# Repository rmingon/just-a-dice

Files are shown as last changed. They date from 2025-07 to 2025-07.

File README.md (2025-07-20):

# Just a Dice

An electronic dice based on the CH32V003 RISC-V microcontroller with bottom-mounted switch activation.

video (https://www.youtube.com/shorts/9gwGjO6Ar-I)

## Overview

This project is a compact electronic dice that uses bottom-mounted switch buttons for activation. Simply press the PCB from the bottom to activate the switches and generate a random number displayed on 6 LEDs arranged in a traditional dice pattern.

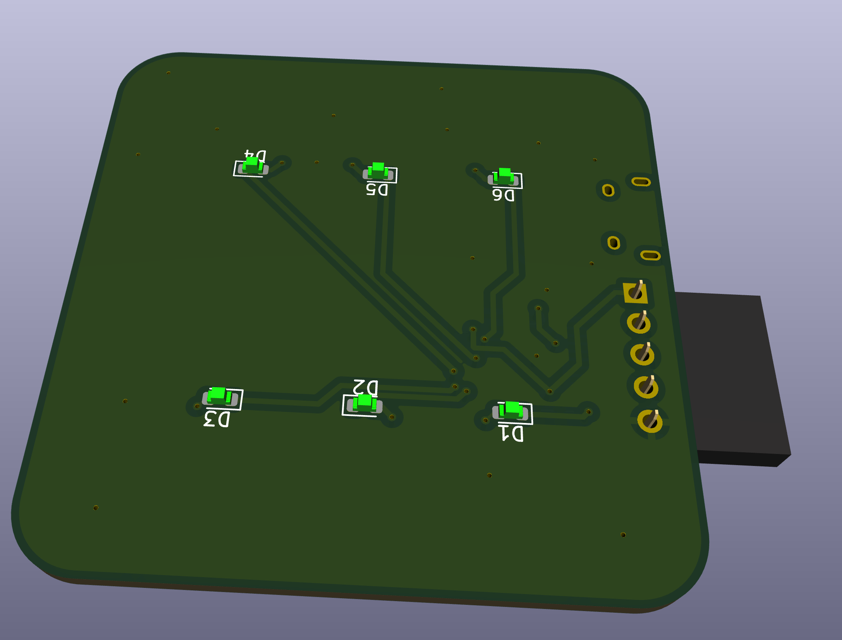
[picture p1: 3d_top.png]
PCB Top View

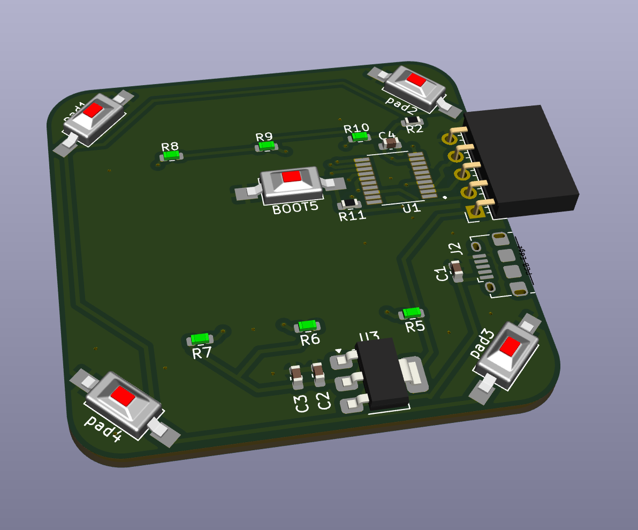
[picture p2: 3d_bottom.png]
PCB Bottom View


## Schematic and PCB Layout

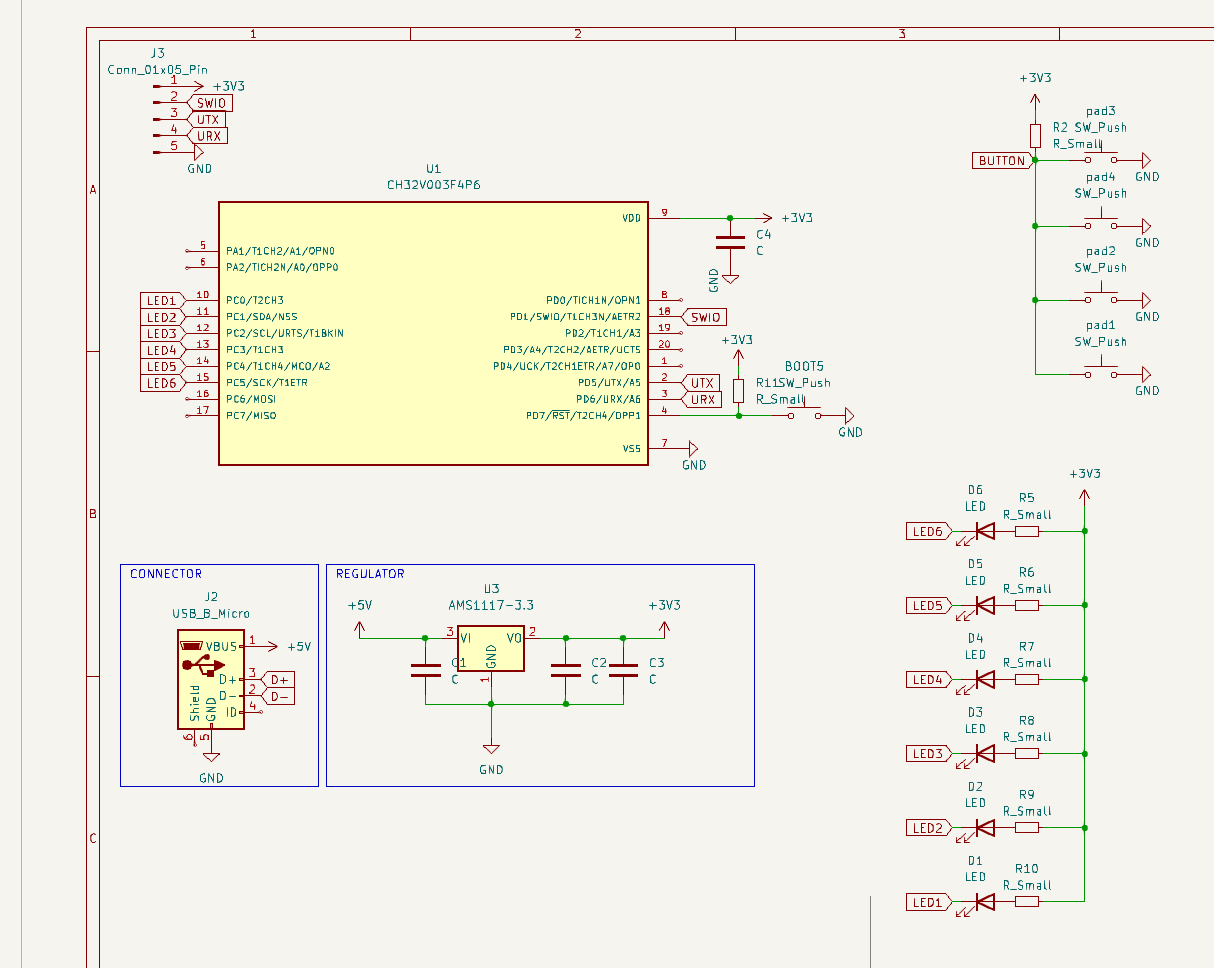
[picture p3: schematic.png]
Schematic

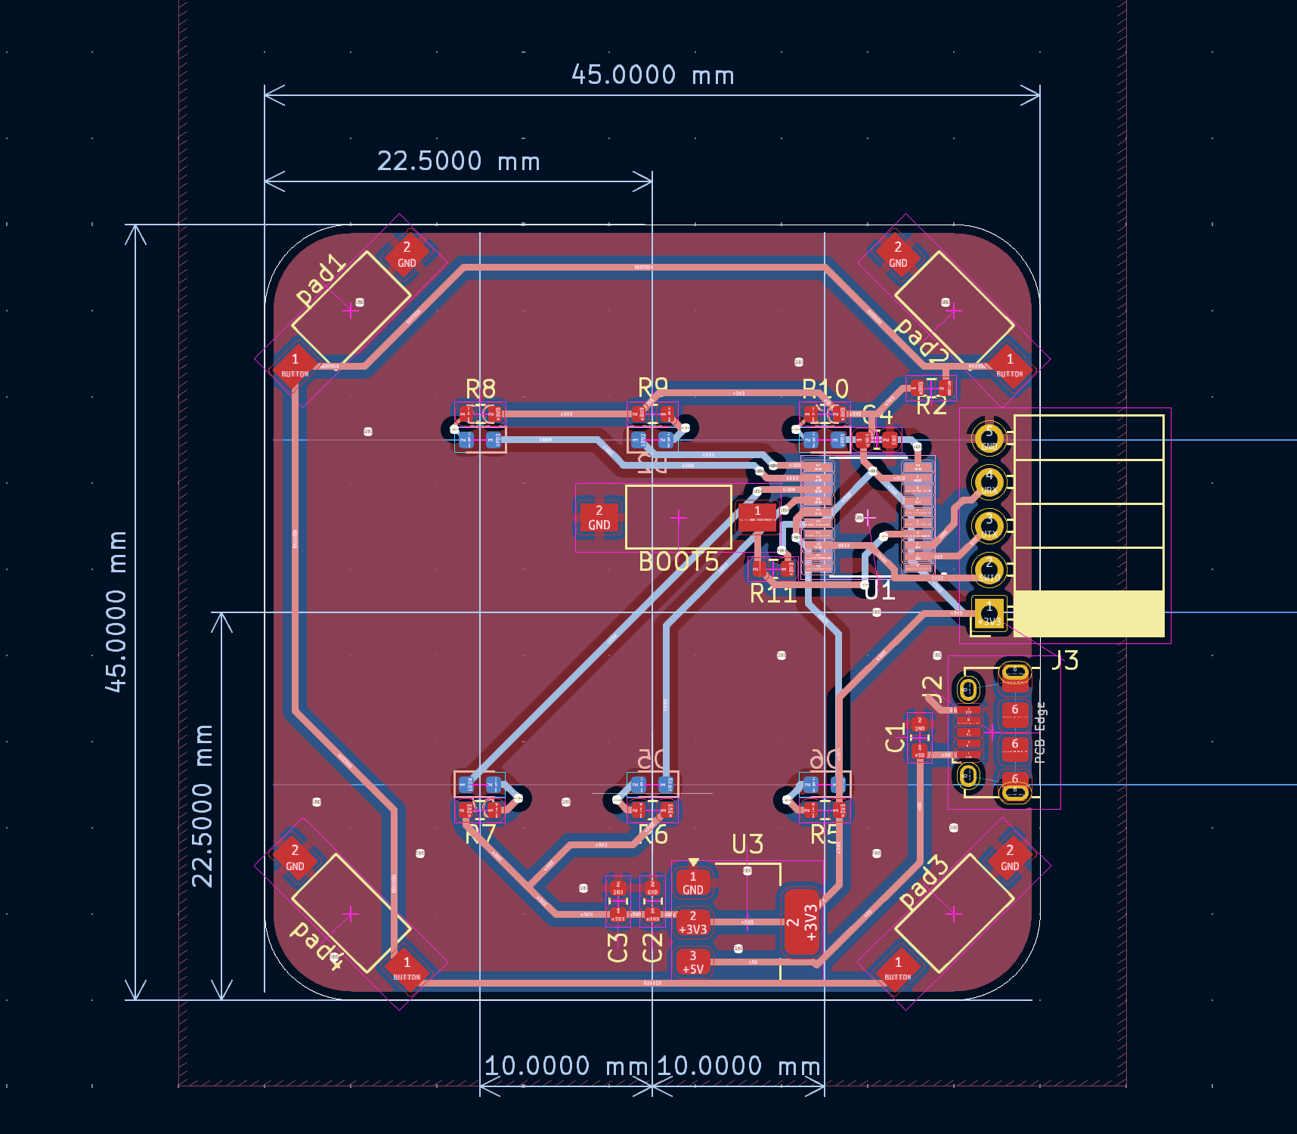
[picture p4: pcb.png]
PCB Layout


## Hardware Features

- **Microcontroller**: CH32V003F4P6 (RISC-V 32-bit)
- **Display**: 6 LEDs arranged in dice pattern (D1-D6)
- **Input**: 4 touch-sensitive pads on bottom (pad1-pad4)
- **Power**: Micro USB connector with onboard 3.3V regulation
- **Programming**: SWD interface with BOOT switch
- **Dimensions**: 45mm x 45mm PCB

## Components

- **U1**: CH32V003F4P6 microcontroller
- **U3**: AMS1117-3.3 voltage regulator
- **D1-D6**: LEDs for dice display
- **R5-R10**: Current limiting resistors for LEDs
- **J2**: Micro USB connector
- **J3**: SWD programming header
- **BOOT5**: Boot mode switch
- **C1-C4**: Decoupling capacitors

## How It Works

1. Power the device via micro USB
2. Press anywhere on the bottom of the PCB (touch pads)
3. The microcontroller generates a random number (1-6)
4. The corresponding LED pattern displays the result

## Programming

The CH32V003 can be programmed via the SWD interface using the onboard programming header (J3). Hold the BOOT switch while powering on to enter programming mode.

## License

This project is licensed under the CERN Open Hardware Licence Version 2 - Strongly Reciprocal (CERN-OHL-S).

## Files

- `hardware/`: KiCad PCB design files
- `schematic.png`: Circuit schematic
- `pcb.png`: PCB layout
- `3d_top.png`: 3D render of PCB top
- `3d_bottom.png`: 3D render of PCB bottom showing touch pads

## Getting Started

1. Assemble the PCB with all components
2. Program the CH32V003 with dice firmware
3. Connect via micro USB
4. Press the bottom to roll the dice!

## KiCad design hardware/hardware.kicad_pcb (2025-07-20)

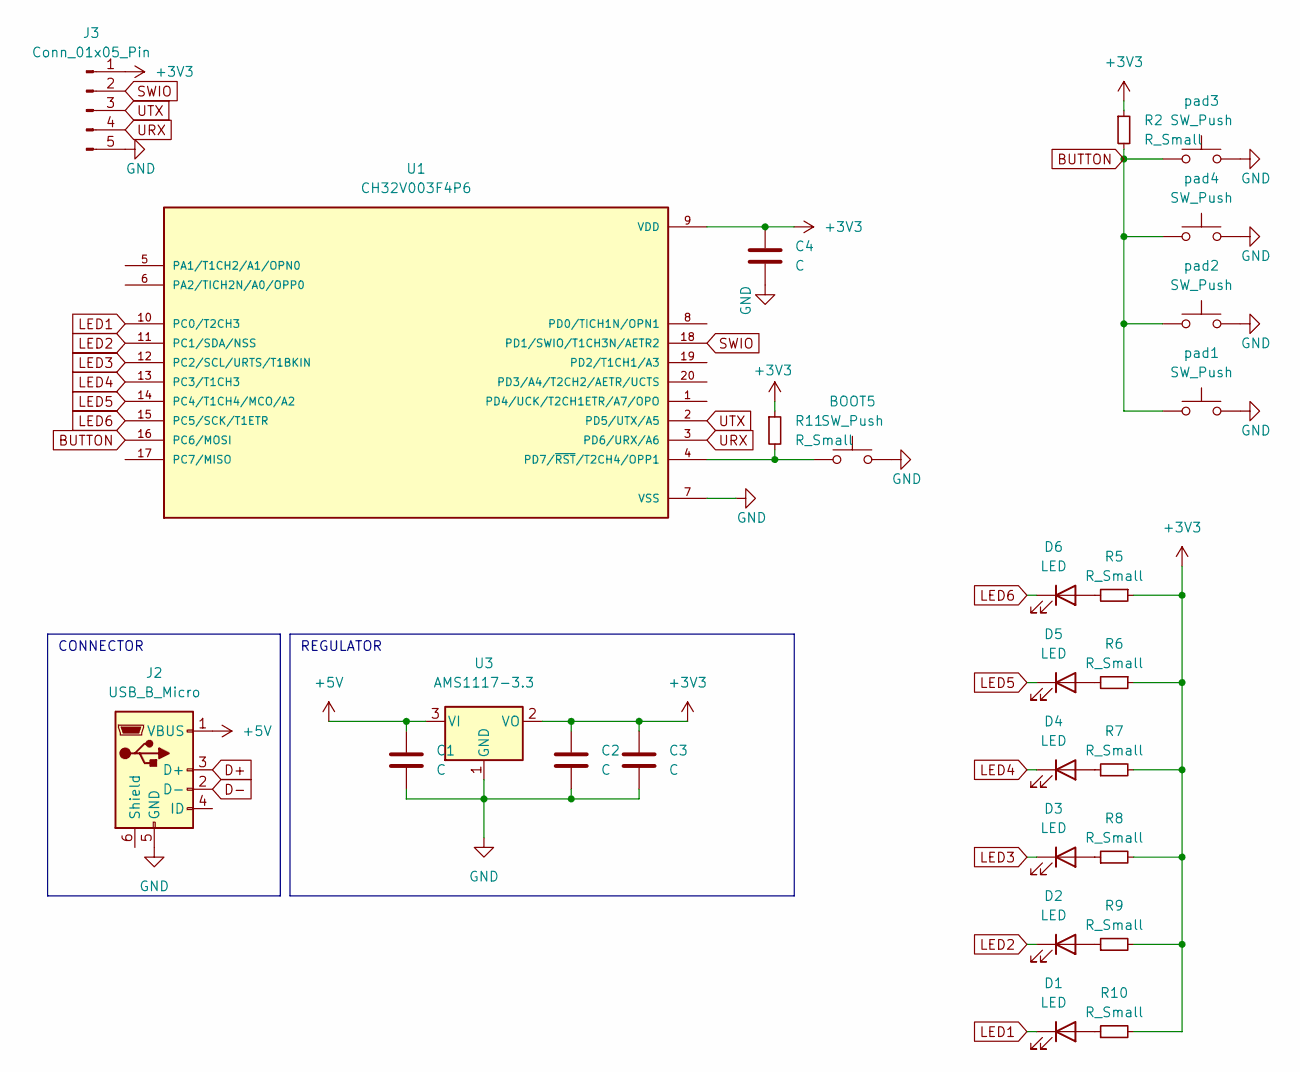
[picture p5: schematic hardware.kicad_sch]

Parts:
BOOT5: SW_Push; SW_SPST_FSMSM
C1, C2, C3, C4: C; C_0603_1608Metric
D1, D2, D3, D4, D5, D6: LED; LED_0603_1608Metric
J2: USB_B_Micro; USB_Micro-B_Amphenol_10118194_Horizontal
J3: Conn_01x05_Pin; PinSocket_1x05_P2.54mm_Horizontal
R2, R5, R6, R7, R8, R9, R10, R11: R_Small; R_0603_1608Metric
U1: CH32V003F4P6; SOP65P640X121-20N; PARTREV 1.4
U3: AMS1117-3.3; SOT-223-3_TabPin2
pad1, pad2, pad3, pad4: SW_Push; SW_SPST_FSMSM

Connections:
+3V3: C2.1, C3.1, C4.1, J3.1, R2.1, R5.1, R6.1, R7.2, R8.2, R9.2, R10.2, R11.1, U1.9 (VDD), U3.2 (VO)
+5V: C1.1, J2.1 (VBUS), U3.3 (VI)
BUTTON: R2.2, U1.16 (PC6/MOSI), pad1.1, pad2.1, pad3.1, pad4.1
D+: J2.3 (D+)
D-: J2.2 (D-)
GND: BOOT5.2, C1.2, C2.2, C3.2, C4.2, J2.5 (GND), J3.5, U1.7 (VSS), U3.1 (GND), pad1.2, pad2.2, pad3.2, pad4.2
LED1: D1.1 (K), U1.10 (PC0/T2CH3)
LED2: D2.1 (K), U1.11 (PC1/SDA/NSS)
LED3: D3.1 (K), U1.12 (PC2/SCL/URTS/T1BKIN)
LED4: D4.1 (K), U1.13 (PC3/T1CH3)
LED5: D5.1 (K), U1.14 (PC4/T1CH4/MCO/A2)
LED6: D6.1 (K), U1.15 (PC5/SCK/T1ETR)
unnamed: D1.2 (A), R10.1
unnamed: D2.2 (A), R9.1
unnamed: D3.2 (A), R8.1
unnamed: D4.2 (A), R7.1
unnamed: D5.2 (A), R6.2
unnamed: D6.2 (A), R5.2
unnamed: BOOT5.1, R11.2, U1.4 (PD7/~RST/T2CH4/OPP1)
SWIO: J3.2, U1.18 (PD1/SWIO/T1CH3N/AETR2)
URX: J3.4, U1.3 (PD6/URX/A6)
UTX: J3.3, U1.2 (PD5/UTX/A5)

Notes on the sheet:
CONNECTOR
REGULATOR

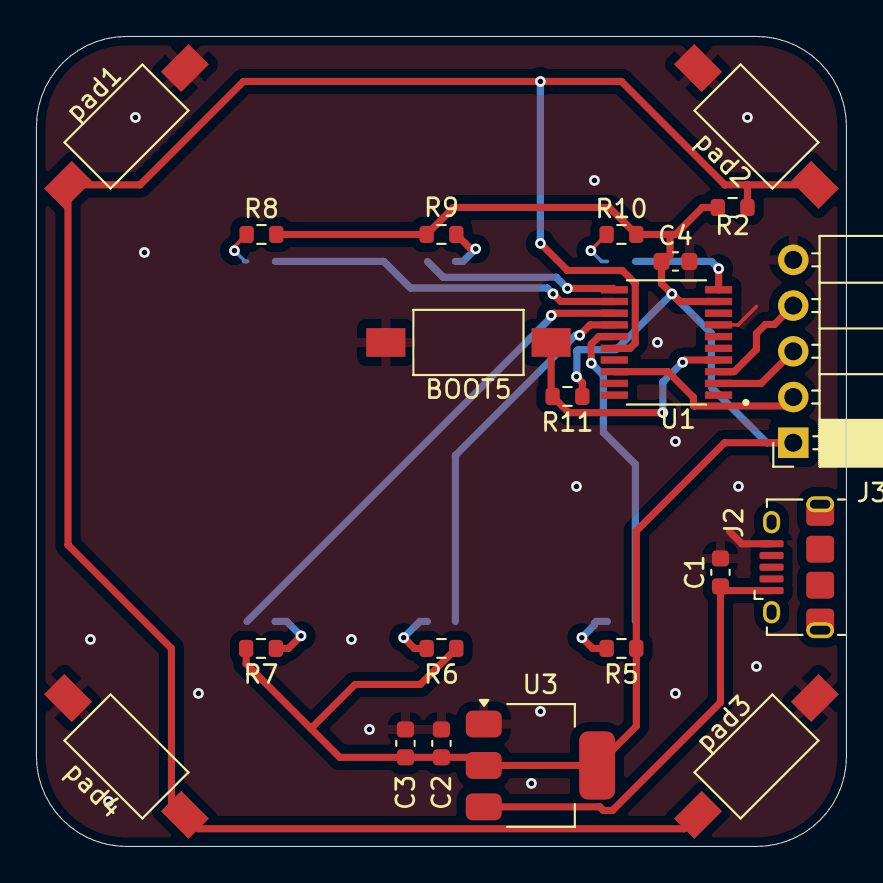
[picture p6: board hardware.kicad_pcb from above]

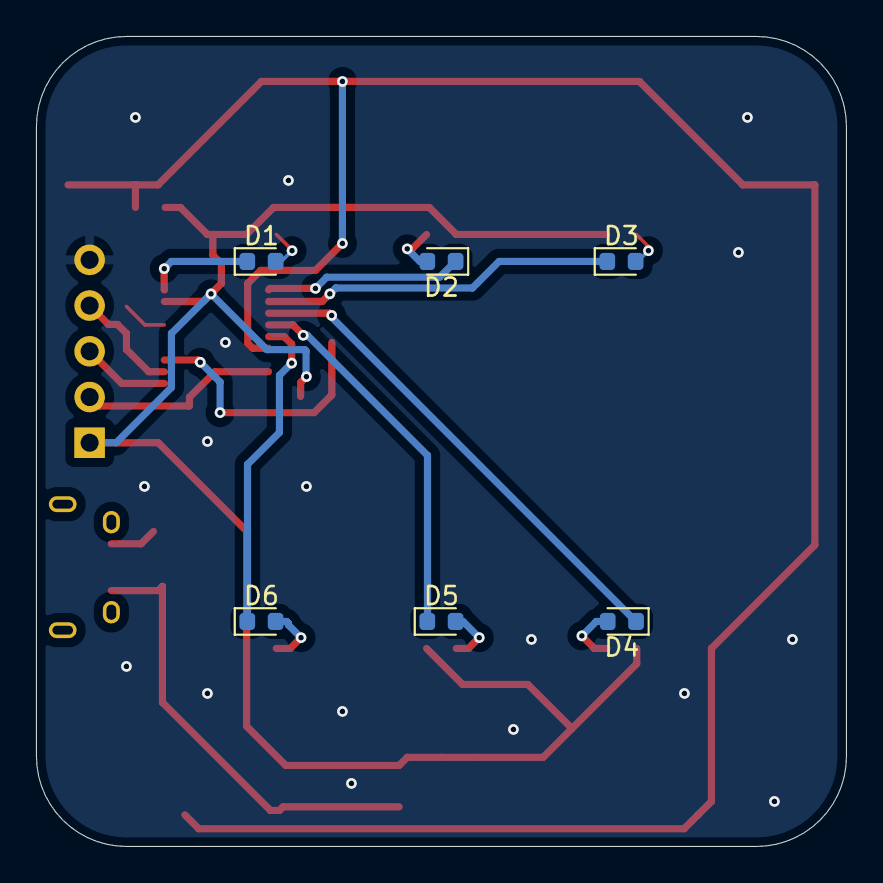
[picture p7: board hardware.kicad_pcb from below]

Board: 2 copper layers, 45.0 x 45.0 mm, 27 parts (6 on the bottom side), 20 nets.

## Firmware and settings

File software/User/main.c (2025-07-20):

#include "debug.h"
#include "ch32v00x.h"
#include "ch32v00x_gpio.h"
#include "ch32v00x_rcc.h"

// LED pin definitions (PC0-PC5)
#define LED_PORT GPIOC
#define LED0_PIN GPIO_Pin_0
#define LED1_PIN GPIO_Pin_1
#define LED2_PIN GPIO_Pin_2
#define LED3_PIN GPIO_Pin_3
#define LED4_PIN GPIO_Pin_4
#define LED5_PIN GPIO_Pin_5

// Button pin definition (PC6)
#define BUTTON_PORT GPIOC
#define BUTTON_PIN GPIO_Pin_6

// Dice patterns for LEDs (6 LEDs can represent dice faces 1-6)
// Alternative dice patterns (more dice-like representation)
const uint8_t dice_patterns[7] = {
    0b000000,  // 0 - Not used
    0b000100,  // 1 - Center LED (LED2)
    0b001001,  // 2 - LED0 and LED3
    0b001101,  // 3 - LED0, LED2, LED3
    0b011011,  // 4 - LED0, LED1, LED3, LED4
    0b011111,  // 5 - LED0, LED1, LED2, LED3, LED4
    0b111111   // 6 - All LEDs
};

// Global variables
volatile uint32_t delay_counter = 0;

// Function prototypes
void GPIO_Configuration(void);
void Display_Dice(uint8_t number);
void Clear_LEDs(void);
uint8_t Generate_Random_Dice(void);
void Simple_Delay_ms(uint32_t ms);
void Dice_Animation(void);

// GPIO Configuration
void GPIO_Configuration(void)
{
    GPIO_InitTypeDef GPIO_InitStructure = {0};
    
    // Enable GPIOC clock
    RCC_PB2PeriphClockCmd(RCC_PB2Periph_GPIOC, ENABLE);
    
    // Configure PC0-PC5 as output push-pull for LEDs (inverted logic)
    GPIO_InitStructure.GPIO_Pin = LED0_PIN | LED1_PIN | LED2_PIN | 
                                  LED3_PIN | LED4_PIN | LED5_PIN;
    GPIO_InitStructure.GPIO_Mode = GPIO_Mode_Out_PP;
    GPIO_InitStructure.GPIO_Speed = GPIO_Speed_30MHz;
    GPIO_Init(LED_PORT, &GPIO_InitStructure);
    
    // Configure PC6 as input with pull-up for button
    GPIO_InitStructure.GPIO_Pin = BUTTON_PIN;
    GPIO_InitStructure.GPIO_Mode = GPIO_Mode_IPU;
    GPIO_Init(BUTTON_PORT, &GPIO_InitStructure);
    
    // Initialize all LEDs as OFF (HIGH for common cathode)
    Clear_LEDs();
}

// Clear all LEDs (turn OFF - set HIGH for common cathode)
void Clear_LEDs(void)
{
    GPIO_SetBits(LED_PORT, LED0_PIN | LED1_PIN | LED2_PIN | 
                 LED3_PIN | LED4_PIN | LED5_PIN);
}

// Display dice number on LEDs (inverted logic for common cathode)
void Display_Dice(uint8_t number)
{
    if (number < 1 || number > 6) return;
    
    Clear_LEDs(); // Turn all LEDs OFF (HIGH)
    
    uint8_t pattern = dice_patterns[number];
    
    // Turn ON LEDs by setting pins LOW
    if (pattern & 0x01) GPIO_ResetBits(LED_PORT, LED0_PIN);
    if (pattern & 0x02) GPIO_ResetBits(LED_PORT, LED1_PIN);
    if (pattern & 0x04) GPIO_ResetBits(LED_PORT, LED2_PIN);
    if (pattern & 0x08) GPIO_ResetBits(LED_PORT, LED3_PIN);
    if (pattern & 0x10) GPIO_ResetBits(LED_PORT, LED4_PIN);
    if (pattern & 0x20) GPIO_ResetBits(LED_PORT, LED5_PIN);
}

// Simple delay function (blocking)
void Simple_Delay_ms(uint32_t ms)
{
    // Rough delay for 24MHz clock
    for (uint32_t i = 0; i < ms; i++) {
        for (volatile uint32_t j = 0; j < 6000; j++) {
            delay_counter++; // Add randomness to the counter
        }
    }
}

// Generate random dice number (1-6)
uint8_t Generate_Random_Dice(void)
{
    // Simple pseudo-random using delay counter
    static uint32_t seed = 0xACE1;
    
    // Mix in the delay counter for randomness
    seed ^= delay_counter;
    seed = (seed * 1103515245 + 12345) & 0x7FFFFFFF;
    
    return (seed % 6) + 1;
}

// Dice rolling animation
void Dice_Animation(void)
{
    const uint8_t animation_cycles = 15;
    const uint32_t animation_delay = 80; // ms between changes
    
    for (uint8_t i = 0; i < animation_cycles; i++) {
        uint8_t random_num = Generate_Random_Dice();
        Display_Dice(random_num);
        Simple_Delay_ms(animation_delay);
    }
}

// Main function
int main(void)
{
    SystemCoreClockUpdate();
    
    // Initialize USART for debugging (optional)
    USART_Printf_Init(115200);
    printf("CH32V006 Dice Application Started (24MHz HSI)\r\n");
    
    // Configure GPIO
    GPIO_Configuration();
    
    // LED test sequence to verify all LEDs work
    printf("Testing all LEDs...\r\n");
    for (uint8_t i = 1; i <= 6; i++) {
        printf("Testing dice face: %d\r\n", i);
        Display_Dice(i);
        Simple_Delay_ms(500);
    }
    
    // Initial display - show "1"
    Display_Dice(1);
    
    printf("Press button on PC6 to roll the dice!\r\n");
    printf("Button: PC6 → Button → GND (with pull-up)\r\n");
    
    uint8_t last_button_state = 1;  // Button not pressed initially
    
    while(1)
    {
        // Read button state directly
        uint8_t button_state = GPIO_ReadInputDataBit(BUTTON_PORT, BUTTON_PIN);
        
        // Detect button press (transition from HIGH to LOW)
        if (last_button_state == 1 && button_state == 0) {
            printf("Button pressed! Rolling dice...\r\n");
            
            // Simple debounce delay
            Simple_Delay_ms(50);
            
            // Play dice animation
            Dice_Animation();
            
            // Generate final random number
            uint8_t dice_result = Generate_Random_Dice();
            
            // Display result
            Display_Dice(dice_result);
            
            printf("Dice result: %d\r\n", dice_result);
            
            // Wait for button release to prevent multiple triggers
            while (GPIO_ReadInputDataBit(BUTTON_PORT, BUTTON_PIN) == 0) {
                Simple_Delay_ms(10);
            }
            
            // Additional delay after release
            Simple_Delay_ms(200);
        }
        
        last_button_state = button_state;
        
        // Small delay in main loop to add randomness
        Simple_Delay_ms(1);
    }
}

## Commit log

2025-07-07 add pcb + schematic with wiring
    [hardware.kicad_pcb, hardware.kicad_sch]
2025-07-07 add 3D models and schematic images
2025-07-07 update README.md to include schematic and PCB layout images
2025-07-07 fix button
    [hardware.kicad_pcb, hardware.kicad_sch]
2025-07-07 fix mcu ground issue
    [hardware.kicad_pcb]
2025-07-20 add code
    [hardware.kicad_pcb, hardware.kicad_sch]
